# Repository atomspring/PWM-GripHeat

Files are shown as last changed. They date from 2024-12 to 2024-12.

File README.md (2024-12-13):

# PWM-GripHeat
Rugged PWM control for a grip heater using an attiny85 and a beefy NMOS, supporting a dual color or RGB indicator, with careful attention paid to power usage.

KiCad 8.0 Schematics and PCB files are (as expected) under the "hardware" folder, firmware is under the "firmware" folder.

Cost for a single board was TODO: fill in total costs, total including optional mechanical components was TODO:

## Hardware
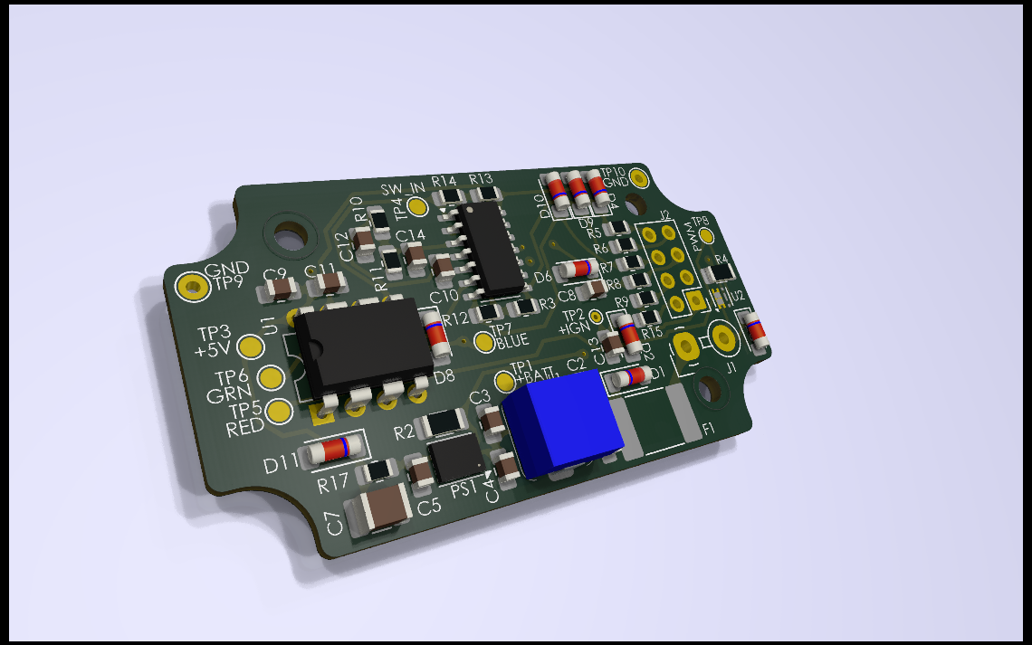
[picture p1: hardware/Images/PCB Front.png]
Front render of PCB
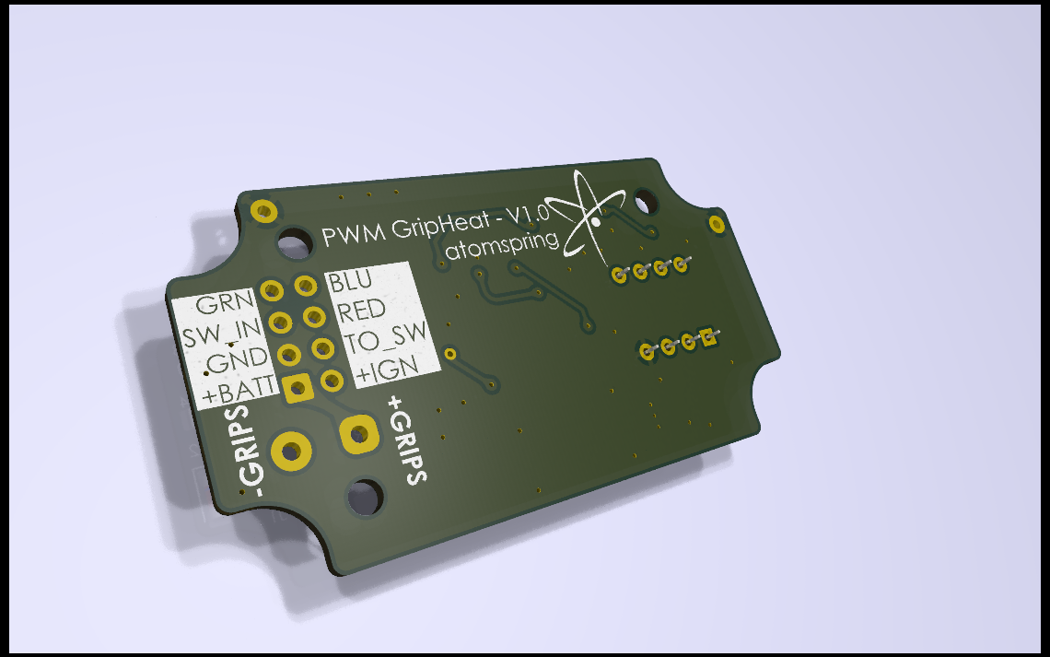
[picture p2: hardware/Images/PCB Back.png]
Render of backside for PCB


The BOM (bill-of-materials) is relatively short, holding all mechanical components in [here](<hardware/bom/Mechanical BOM.md>), and the PCB components [here](<hardware/bom/BOM-PWM GripHeat-1.0.html>).

Assembly should take about an hour's work with the right tools. I use lead-free solder paste for all my work, with the PCB itself using ENIG for all pads. Soldering is sped up by using a hand-held hot air reflow gun, but all pads are big enough to facilitate hand soldering.

## Firmware
I'm using PlatformIO on VSCodium to write the fairly simple firmware, build steps:
1. Item 1
1. rr
1. te

## License
This project is:
- Software: GPL3 protected
- Hardware: CERN-OHL-S-2.0 (https://spdx.org/licenses/CERN-OHL-S-2.0.html)

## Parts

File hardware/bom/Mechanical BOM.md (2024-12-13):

# Mechanical BOM for PWM GripHeat v1.0

<i>Note:</i> I'm wiring this up to be my motorcycle start switch, as well as heater control, hence a two button momentary switch.

Description | Manufacturer P/N | QTY | Total Price | Link 1 | Link 2
---|---|---|---|---|---
Dual momentary Handlebar Switch |  | 1 |  $20 | https://www.ebay.com/itm/174391393715 | https://www.amazon.com/FVMOTO-Buttons-Momentary-Handlebar-Universal/dp/B0CDPY4V7W
Diffused 5mm RGB LED (common cathode preferred)| HV-5RGB60 | 1 | $5 | https://www.digikey.com/en/products/detail/inolux/HV-5RGB60/7604616
8 conductor 22AWG cable |West Penn Wire 3271  |6ft / 2m | $5 | https://www.ebay.com/itm/154273713858
IP68 Enclosure | Hammond W1551WHBK | 1 | $6 | https://www.digikey.com/en/products/detail/hammond-manufacturing/1551WHBK/16675213

Optional upgrades:
Description | Manufacturer P/N | QTY |Total Price | Link 1 | Link 2
---|---|---|---|---|---
Halo illuminated momentary switch | BMA-12R| 2 | $12 | https://www.ebay.com/itm/123011828672
DIP-8 IC Socket | 245-08-1-03 |1 | $0.21 | https://www.digikey.com/en/products/detail/cnc-tech/245-08-1-03/3441579

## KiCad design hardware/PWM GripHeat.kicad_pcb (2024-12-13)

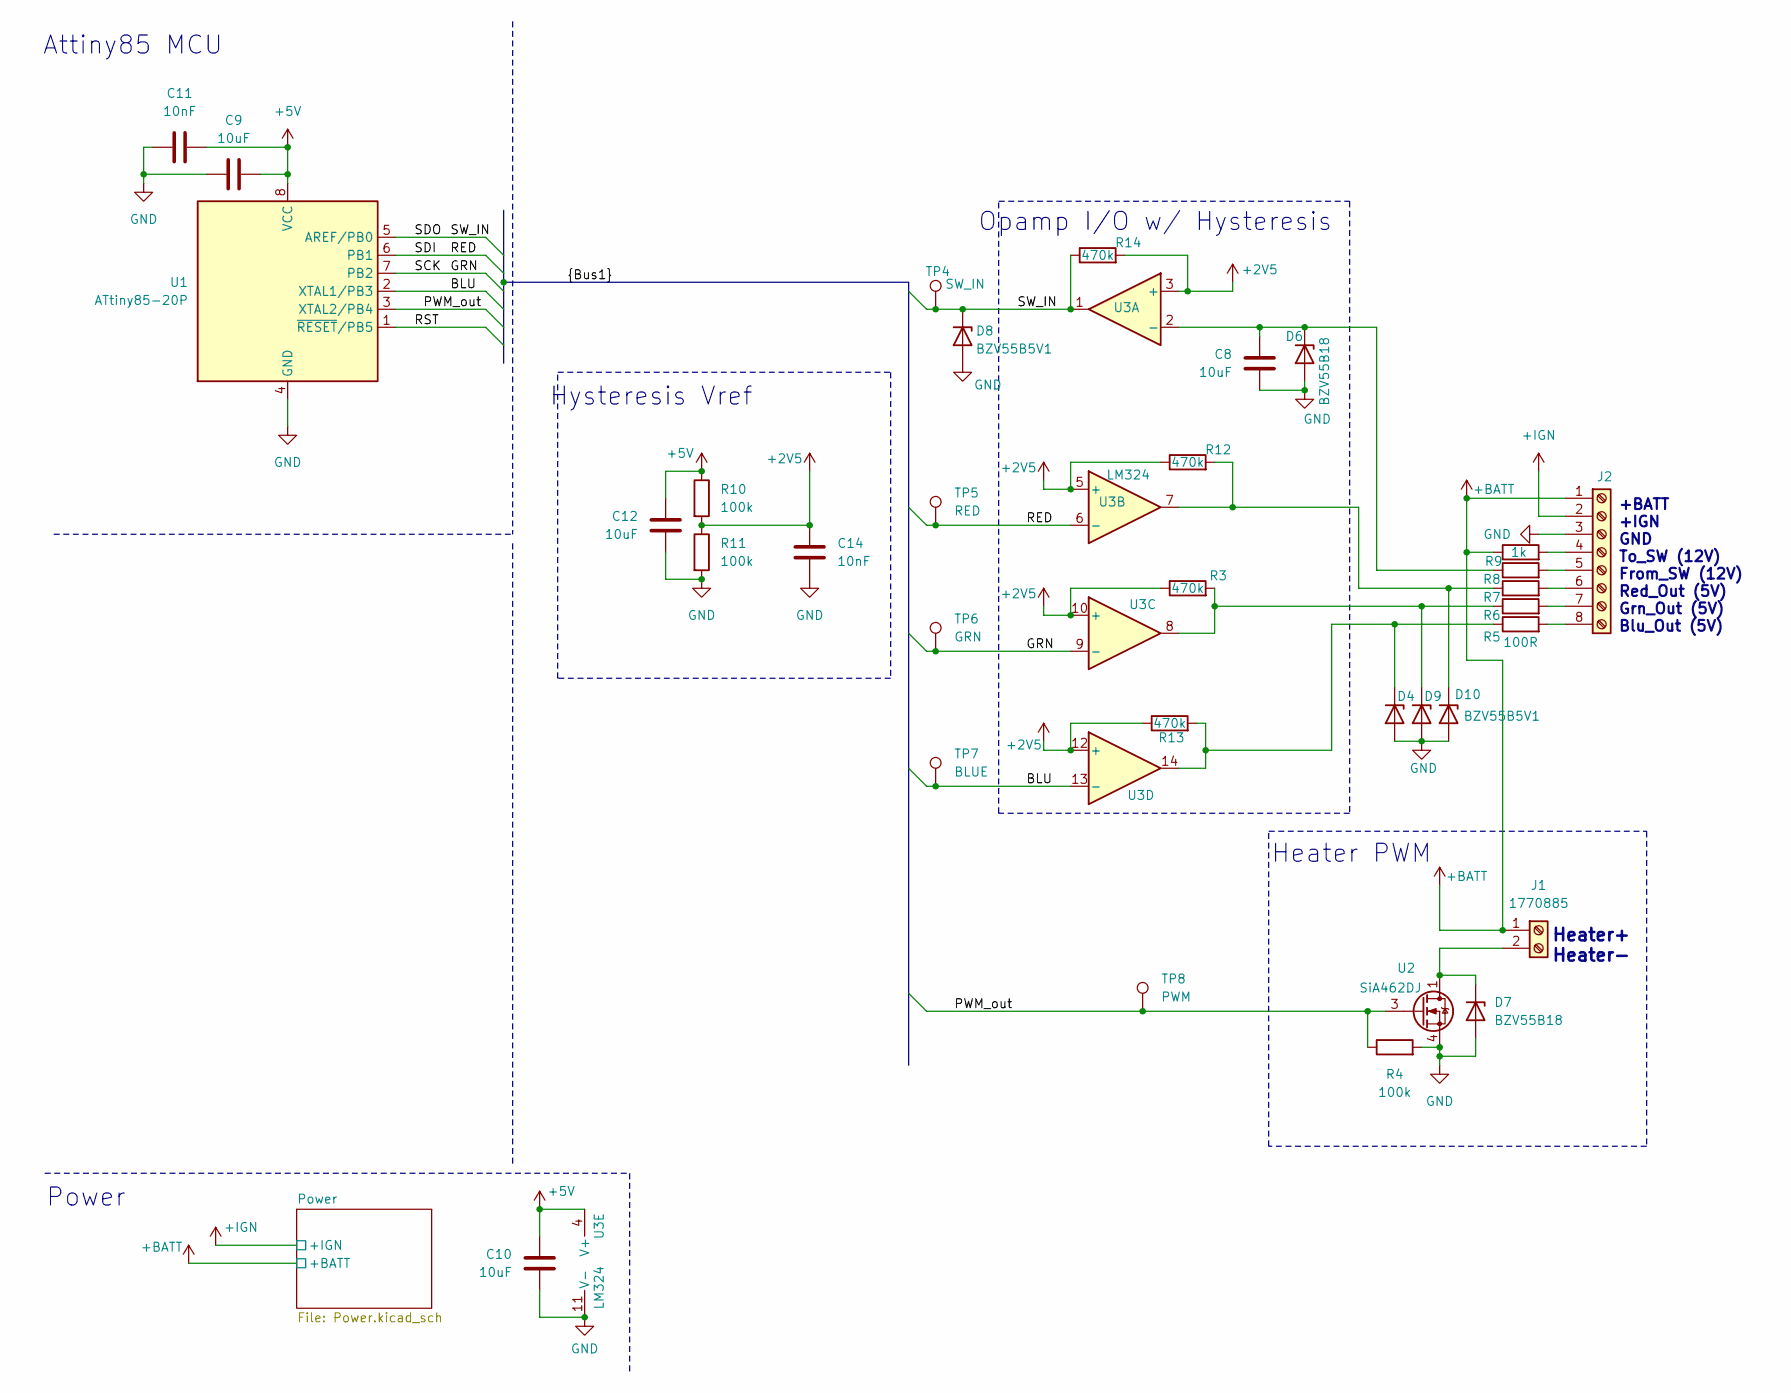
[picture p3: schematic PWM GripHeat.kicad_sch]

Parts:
C8, C9, C10, C12: 10uF; C_0805_2012Metric_Pad1.18x1.45mm_HandSolder; Voltage Rating 100v
C11, C14: 10nF; C_0805_2012Metric_Pad1.18x1.45mm_HandSolder
D4, D8, D9, D10: BZV55B5V1; D_MiniMELF
D6, D7: BZV55B18; D_MiniMELF
J1: 1770885; TerminalBlock_MaiXu_MX126-5.0-02P_1x02_P5.00mm
J2: Screw_Terminal_01x08; PinHeader_2x04_P2.54mm_Vertical
R3, R12, R13, R14: 470k; R_0805_2012Metric_Pad1.20x1.40mm_HandSolder
R4: 100k; R_1206_3216Metric_Pad1.30x1.75mm_HandSolder
R5, R6, R7, R8: 100R; R_0805_2012Metric_Pad1.20x1.40mm_HandSolder
R9: 1k; R_0805_2012Metric_Pad1.20x1.40mm_HandSolder
R10, R11: 100k; R_0805_2012Metric_Pad1.20x1.40mm_HandSolder
TP4: SW_IN; TestPoint_Pad_D1.5mm
TP5: RED; TestPoint_Pad_D1.5mm
TP6: GRN; TestPoint_Pad_D1.5mm
TP7: BLUE; TestPoint_Pad_D1.5mm
TP8: PWM; TestPoint_Pad_D1.5mm
U1: ATtiny85-20P; DIP-8_W7.62mm
U2: SiA462DJ; Vishay_PowerPAK_SC70-6L_Single
U3: LM324; SOIC-14_3.9x8.7mm_P1.27mm

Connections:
+2V5: C14.2, R3.1, R10.2, R11.1, R12.1, R13.1, R14.2, U3.3 (+), U3.5 (+), U3.10 (+), U3.12 (+)
+5V: C9.2, C10.2, C11.2, C12.2, R10.1, U1.8 (VCC), U3.4 (V+); also elsewhere on the board
+BATT: J1.1, J2.1, R9.1; also elsewhere on the board
+IGN: J2.2; also elsewhere on the board
/BLU: TP7.1, U1.2 (XTAL1/PB3), U3.13 (-)
/GRN: TP6.1, U1.7 (PB2), U3.9 (-)
/PWM_out: R4.1, TP8.1, U1.3 (XTAL2/PB4), U2.3 (G)
/RED: TP5.1, U1.6 (PB1), U3.6 (-)
/RST: U1.1 (~RESET/PB5)
/SDO: D8.1 (K), R14.1, TP4.1, U1.5 (AREF/PB0), U3.1
GND: C8.1, C9.1, C10.1, C11.1, C12.1, C14.1, D4.2 (A), D6.2 (A), D7.2 (A), D8.2 (A), D9.2 (A), D10.2 (A), J2.3, R4.2, R11.2, U1.4 (GND), U2.4 (S), U3.11 (V-); also elsewhere on the board
unnamed: D4.1 (K), R5.1, R13.2, U3.14
unnamed: C8.2, D6.1 (K), R8.1, U3.2 (-)
unnamed: D7.1 (K), J1.2, U2.1 (D)
unnamed: D9.1 (K), R3.2, R6.1, U3.8
unnamed: D10.1 (K), R7.1, R12.2, U3.7
unnamed: J2.4, R9.2
unnamed: J2.5, R8.2
unnamed: J2.6, R7.2
unnamed: J2.7, R6.2
unnamed: J2.8, R5.2

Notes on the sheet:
Hysteresis Vref
+BATT +IGN GND To_SW (12V) From_SW (12V) Red_Out (5V) Grn_Out (5V) Blu_Out (5V)
Heater PWM
Opamp I/O w/ Hysteresis
Heater+ Heater-
Attiny85 MCU
Power

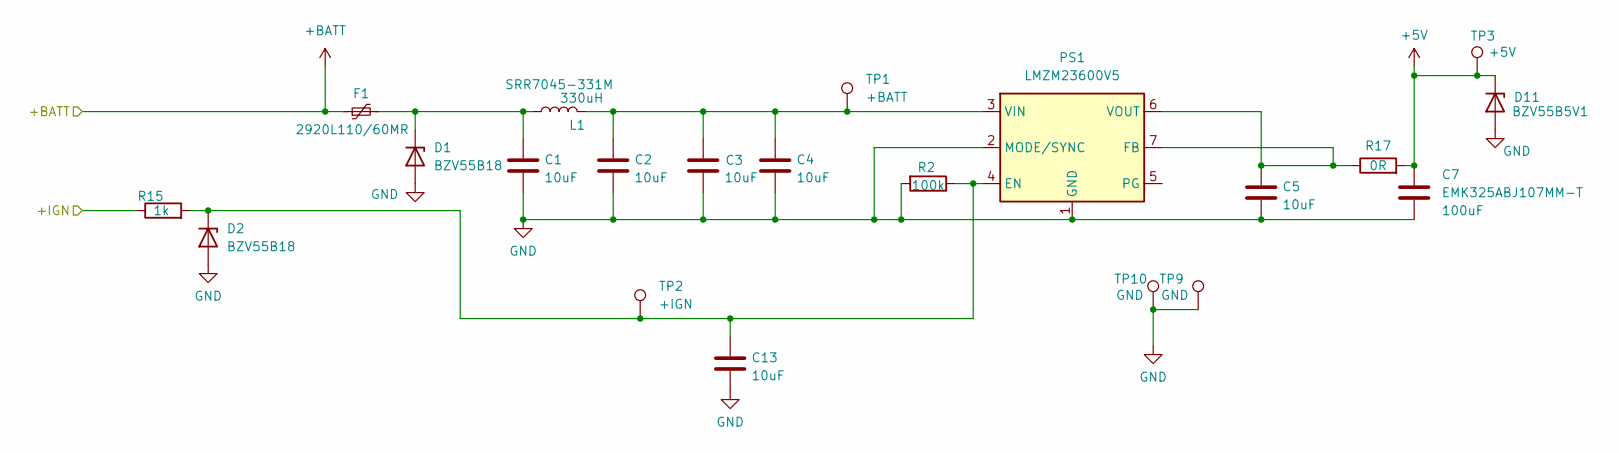
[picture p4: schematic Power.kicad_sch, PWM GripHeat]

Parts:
C1, C2, C3, C4, C5, C13: 10uF; C_0805_2012Metric_Pad1.18x1.45mm_HandSolder; Voltage Rating 100v
C7: EMK325ABJ107MM-T; C_1210_3225Metric_Pad1.33x2.70mm_HandSolder; Voltage Rating 16v
D1, D2: BZV55B18; D_MiniMELF
D11: BZV55B5V1; D_MiniMELF
F1: Polyfuse_Small; Fuse_2920_7451Metric_Pad2.10x5.45mm_HandSolder; MPN 2920L110/60MR
L1: 330uH; L_Bourns_SRR7045; MPN SRR7045-331M
PS1: LMZM23600V5; Texas_SIL0010A_MicroSiP-10-1EP_3.8x3mm_P0.6mm_EP0.7x2.9mm_T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
R2: 100k; R_1206_3216Metric_Pad1.30x1.75mm_HandSolder
R15: 1k; R_0805_2012Metric_Pad1.20x1.40mm_HandSolder
R17: 0R; R_0805_2012Metric_Pad1.20x1.40mm_HandSolder
TP1: +BATT; TestPoint_Pad_D1.5mm
TP2: +IGN; TestPoint_THTPad_D1.0mm_Drill0.5mm
TP3: +5V; TestPoint_Pad_D1.5mm
TP9, TP10: GND; TestPoint_THTPad_D2.0mm_Drill1.0mm

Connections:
+5V: C7.1, D11.1 (K), R17.2, TP3.1; also elsewhere on the board
+BATT: F1.1; also elsewhere on the board
+IGN: R15.1; also elsewhere on the board
GND: C1.2, C2.2, C3.2, C4.2, C5.2, C7.2, C13.2, D1.2 (A), D2.2 (A), D11.2 (A), PS1.1 (GND), PS1.2 (MODE/SYNC), PS1.11 (GND), R2.2, TP9.1, TP10.1; also elsewhere on the board
unnamed: C1.1, D1.1 (K), F1.2, L1.1
unnamed: C13.1, D2.1 (K), PS1.4 (EN), R2.1, R15.2, TP2.1
unnamed: C5.1, PS1.6 (VOUT), PS1.7 (FB), R17.1
unnamed: C2.1, C3.1, C4.1, L1.2, PS1.3 (VIN), TP1.1

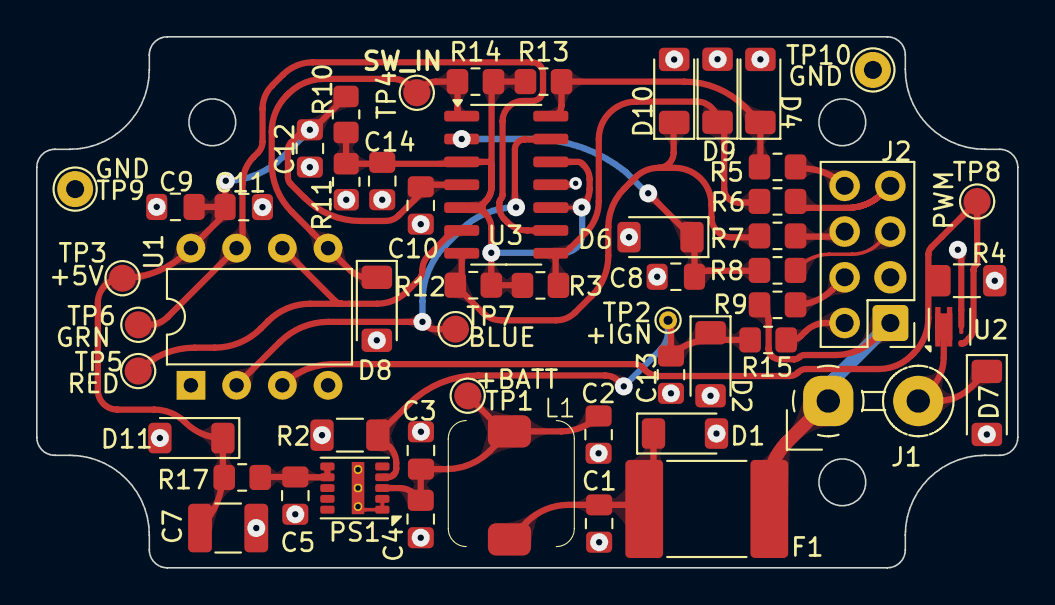
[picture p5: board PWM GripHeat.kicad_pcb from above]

Board: 2 copper layers, 54.5 x 29.5 mm, 55 parts (0 on the bottom side), 24 nets.

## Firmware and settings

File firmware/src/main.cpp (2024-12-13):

#include <Arduino.h>

// put function declarations here:
int myFunction(int, int);

void setup() {
  // put your setup code here, to run once:
  int result = myFunction(2, 3);
}

void loop() {
  // put your main code here, to run repeatedly:
}

// put function definitions here:
int myFunction(int x, int y) {
  return x + y;
}

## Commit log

2024-11-28 Getting there
    [PWM GripHeat.kicad_pcb, PWM GripHeat.kicad_sch]
2024-11-28 Add power drawing
    [Power.kicad_sch]
2024-12-01 PCB Basic outline
    [PWM GripHeat.kicad_pcb, PWM GripHeat.kicad_sch, Power.kicad_sch]
2024-12-02 Pre DRC, almost done!
    [PWM GripHeat.kicad_pcb, PWM GripHeat.kicad_sch, Power.kicad_sch]
2024-12-03 V1.0 release
    [PWM GripHeat.kicad_pcb]
2024-12-11 Improving documentation
    [PWM GripHeat.kicad_pcb, Power.kicad_sch]
2024-12-13 Adding basic firmware, further docs
    [PWM GripHeat.kicad_pcb]
